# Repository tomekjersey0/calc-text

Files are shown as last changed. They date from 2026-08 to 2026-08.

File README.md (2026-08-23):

# CalcText

## What is CalcText?

CalcText is a wireless messaging device enclosed inside a scientific calculator, powered by a single AAA battery. Two units can message each other directly over LoRa, not requiring Wi-Fi, mobile data, or any kind of external infrastructure. The idea came to me from wanting to message a friend who sat far away from me in my maths class without using my phone or shouting. Despite being a little odd, the idea stuck with me.

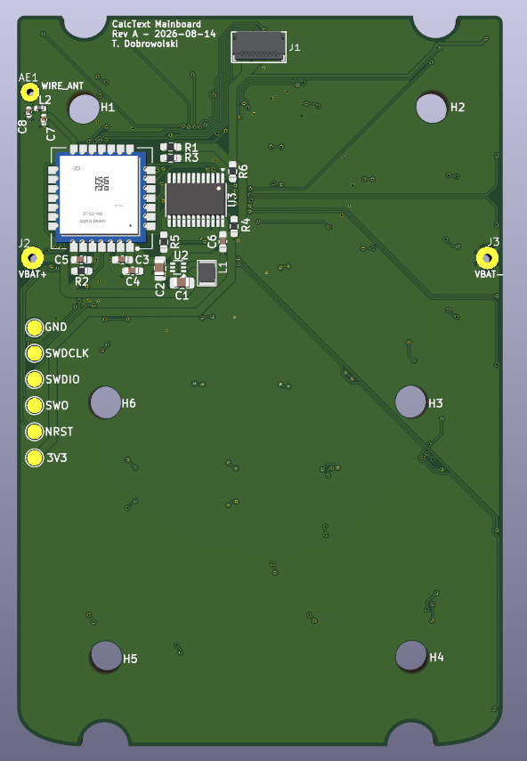
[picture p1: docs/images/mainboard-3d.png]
CalcText Rev A mainboard 3D render


*CalcText Rev A mainboard 3D render.*

## How it works

CalcText replaces all of the internal calculator electronics, including the PCB and LCD screen, whilst making use of some of the existing mechanical features.

CalcText makes use of several electronic components.

| Part | Purpose |
| --- | --- |
| Wio-E5-LE | MCU and LoRa radio module |
| TPS61299 | Boosts AAA voltage to 3.3 V |
| PCAL9535A | GPIO expander, scans original keypad matrix for input |
| HLCD290TB reflective display | Replacement display for calculator |
| Interposer board | Connects display to mainboard |
| ~90 mm wire antenna | Used for 868 MHz LoRa |

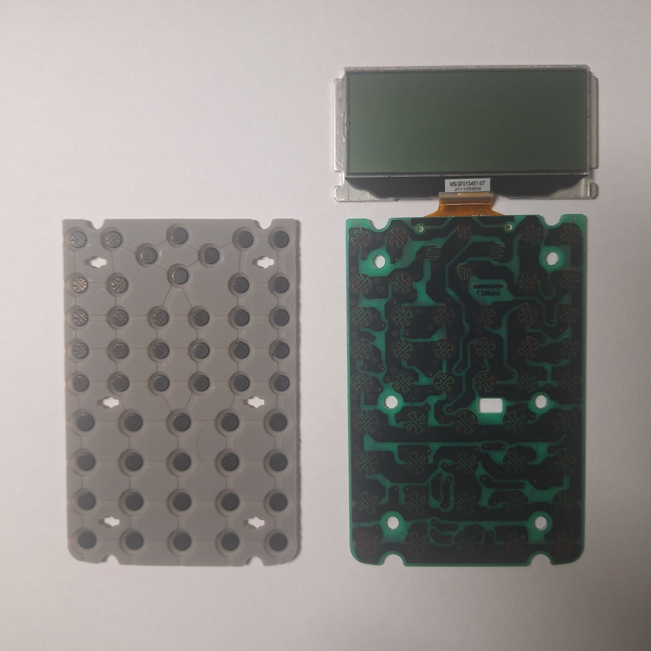
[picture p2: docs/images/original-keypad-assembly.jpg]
Original calculator keypad and PCB


*Original calculator keypad and PCB assembly.*

CalcText makes use of an existing elastomeric keypad that was part of the original calculator. It gives the user a way to interact with the contacts on the PCB. The old contact pattern is therefore replicated on the replacement PCB.

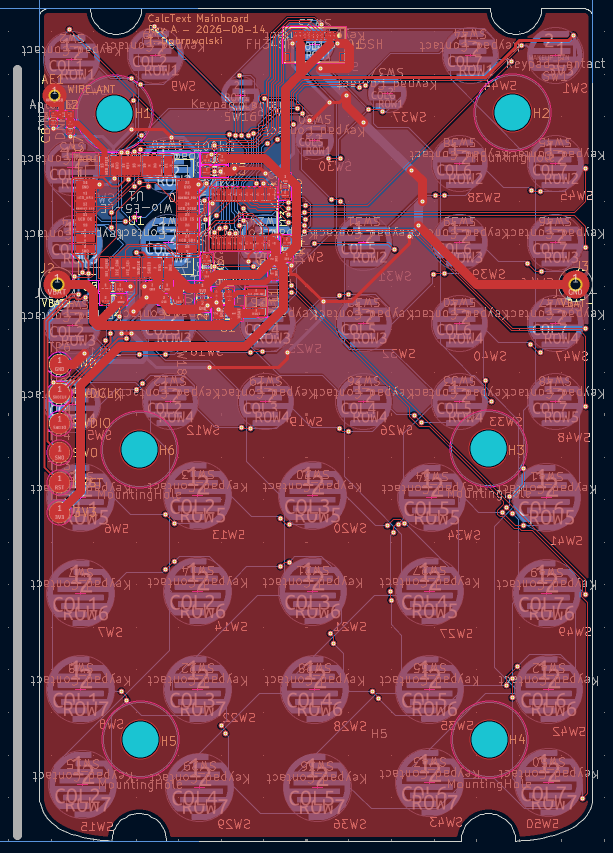
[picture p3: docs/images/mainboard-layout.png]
Rev A mainboard PCB layout


*Rev A mainboard PCB layout.*

A direct FPC connection isn't viable from the reflective display to the mainboard, so an intermediary interposer board is used, to be located on the rear of the display.

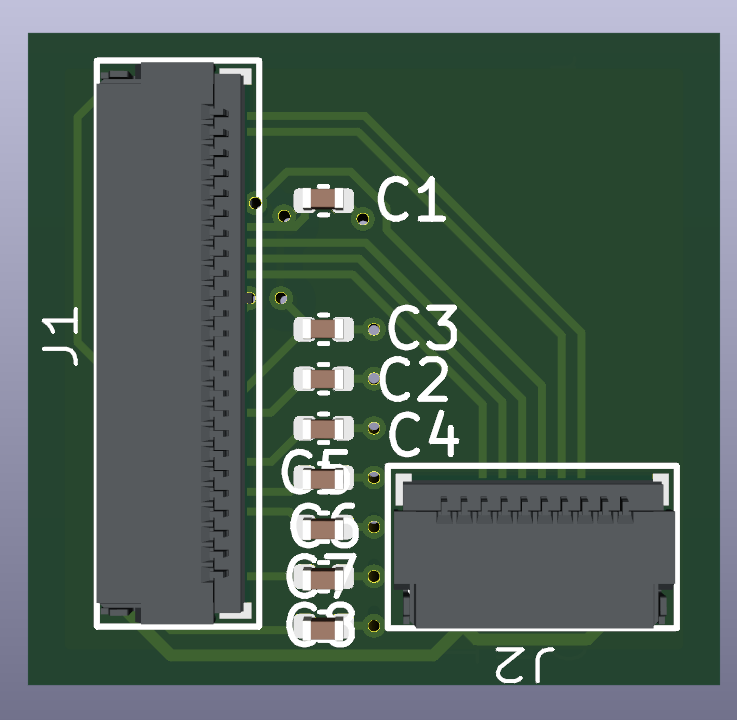
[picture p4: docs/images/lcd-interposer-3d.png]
LCD interposer 3D render


*LCD interposer 3D render.*

## Fitting it inside the calculator

The main challenge is getting everything to fit inside the original enclosure.

| Part to fit | Issue | Resolution |
| --- | --- | --- |
| Mainboard | There are mounting holes, thickness, and outline constraints | Produced acrylic fit test using school equipment and measured original PCB thickness with calipers |
| Display | Larger footprint and thinner than original | Sections of the enclosure can be removed, and PORON foam can secure it |
| Interposer | Unknown FPC landing position due to bend once display is installed | Order screen first and design interposer size based on measured landing position |
| Antenna | Needs sufficient distance from metal and components to ensure good transmission quality | Keep antenna routed down long edge through visible gap, allow it to exit the PCB as far from the display and battery as possible |

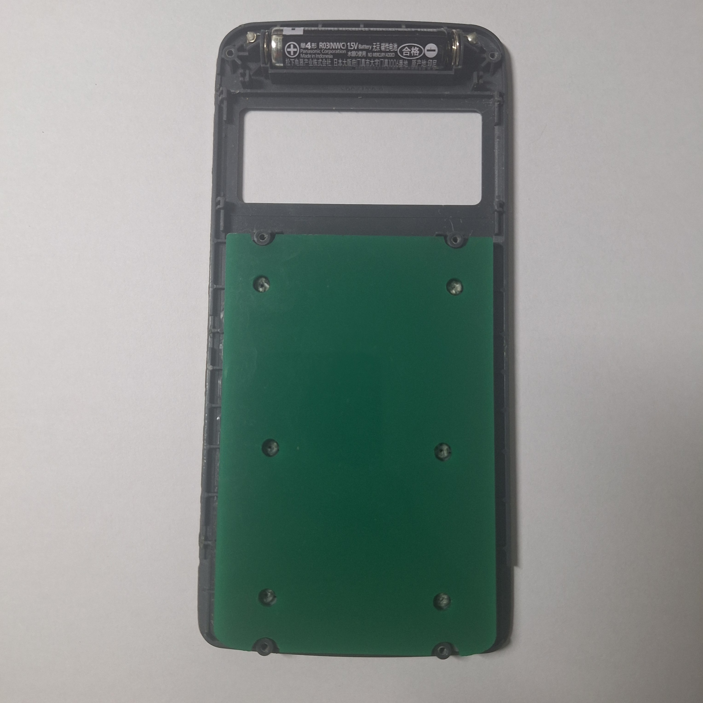
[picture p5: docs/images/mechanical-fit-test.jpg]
Acrylic mainboard fit test inside calculator enclosure


*Acrylic mainboard fit test inside the calculator enclosure + Location of battery.*

## Current status

| Element | Status |
| --- | --- |
| Mainboard schematic | Complete |
| Mainboard layout | Complete |
| Interposer schematic | Complete |
| Interposer layout | Pending display measurements |
| BOM | Complete |
| Physical build | Pending components |
| Funding | Pending review |

## Next steps

1. Submit project for review
2. Order all currently finalised parts
3. Take necessary measurements
4. Complete and order interposer
5. Fully assemble 2 CalcTexts
6. Write firmware
7. Test messaging
8. Tune antenna if necessary
9. Project complete

## BOM

The full BOM can be found in [`bom.csv`](bom.csv).
This BOM covers *two* individual CalcText units.

## Credits

This project was enabled by [Hack Club, Macondo](https://macondo.hackclub.com).

You can access the project's full development journal [here](https://macondo.hackclub.com/projects/16515).

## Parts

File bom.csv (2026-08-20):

Category | Board / Use | Reference | Item | Manufacturer | MPN / Exact spec | Qty per CalcText | Qty for 2 | Owned? | Qty to Buy | Notes
Core electronics | Mainboard | U1 | LoRa MCU module | Seeed Studio | Wio-E5-LE | 1 | 2 | No | 2 | DigiKey cart. Buy exactly 2; no spare currently included.
Power | Mainboard | U2 | Boost converter | Texas Instruments | TPS61299DRLR | 1 | 2 | No | 4 | DigiKey cart: 2 required + 2 spares. Non-A variant is locked.
Keypad | Mainboard | U3 | 16-bit I/O expander | NXP | PCAL9535APW,118 | 1 | 2 | No | 3 | DigiKey cart: 2 required + 1 spare.
Power | Mainboard | L1 | 1 uH power inductor | INPAQ | WIP252010P-1R0ML | 1 | 2 | No | 20 | LCSC C315715. 20-piece MOQ; only 2 required for two units.
RF | Mainboard | L2 | 0 ohm series link | YAGEO | RC0402JR-070RL | 1 | 2 | No | 10 | DigiKey cart: 2 required; buying 10. Keep designator L2.
Power | Mainboard | C1,C2 | 10 uF ceramic capacitor | Samsung Electro-Mechanics | CL21B106KOQNNNE; 10uF ±10%, 16V, X7R, 0805 | 2 | 4 | Yes (20) | 0 | Owned stock.
Decoupling | Mainboard | C3,C5,C6 | 100 nF ceramic capacitor | KEMET | C0603C104K5RACTU; 0.1uF ±10%, 50V, X7R, 0603 | 3 | 6 | Yes (75) | 0 | Owned stock.
Power | Mainboard | C4 | 4.7 uF ceramic capacitor | Samsung Electro-Mechanics | CL10B475KQ8NNNC; 4.7uF ±10%, 6.3V, X7R, 0603 | 1 | 2 | Yes (20) | 0 | Owned stock.
RF | Mainboard | C7,C8 | Pi-network shunt capacitor footprints | — | 0402, DNP | 0 fitted | 0 fitted | N/A | 0 | DNP in Rev A.
Keypad / control | Mainboard | R1-R3 | 100 kOhm resistor | Stackpole Electronics | RMCF0603FT100K | 3 | 6 | Yes (50) | 0 | Owned stock.
Keypad / control | Mainboard | R4-R6 | 10 kOhm resistor | YAGEO | RC0603FR-0710KL | 3 | 6 | Yes (100) | 0 | Owned stock.
Display connection | Mainboard + LCD interposer | Mainboard J1; Interposer J2 | 10-pin FFC connector | Hirose | FH34SRJ-10S-0.5SH(99) | 2 | 4 | No | 5 | DigiKey cart: 4 required + 1 spare. 0.5mm pitch, for 0.3mm FFC.
Display connection | LCD interposer | J1 | 24-pin display FPC connector | Hirose | FH34SRJ-24S-0.5SH(99) | 1 | 2 | No | 3 | DigiKey cart: 2 required + 1 spare. 0.5mm pitch, for ~0.30mm display FPC.
Display decoupling | LCD interposer | C1-C8 | 1 uF ceramic capacitor | TDK | C1005X5R1E105K050BC; 1uF ±10%, 25V, X5R, 0402 | 8 | 16 | No | 25 | DigiKey cart: 16 required; buying 25.
Display | Mechanical / electrical | LCD1 | 2.9in reflective monochrome TFT display | Hicenda | HLCD290TB; ST7305; 168x384; black/white; 24-pin 0.5mm FPC | 1 | 2 | No | 2 | Hicenda has stock. Direct Jersey shipment. Final PI received with correct Jersey delivery address and destination.
RF | Mainboard / enclosure | AE1 | 868 MHz wire antenna | Owned wire | ~86.3mm quarter-wave; insulated solid-core wire ~0.6mm diameter | ~86.3 mm | ~172.6 mm | Yes | 0 | Owned wire is sufficient.
Power / wiring | Mainboard / enclosure | BAT+, BAT- | Battery hookup wire | Owned wire | Insulated solid-core wire ~0.6mm diameter | As needed | As needed | Yes | 0 | Use existing wire stock.
PCB fabrication | Mainboard | PCB | CalcText Rev A mainboard PCB | JLCPCB | 0.8mm, 2-layer, 1oz copper, green soldermask, white silkscreen, HASL with lead | 1 | 2 | No | 5 | JLCPCB minimum/order quantity 5. Current checkout total £3.14 before Ship2Me forwarding.
Donor hardware | Enclosure / keypad | DONOR1 | Compatible donor calculator | Casio / eBay seller | Casio FX-83GTX Scientific Calculator - NO COVER - BLACK | 1 | 2 | Yes (1 donor) | 1 | One donor already owned; buy one additional donor on eBay. Item £14.99, free UK postage, then Ship2Me.
Assembly consumable | Assembly | — | No-clean tack flux | Chip Quik | SMD491-5M | Shared | Shared | No | 1 | DigiKey cart. No-clean, halogen-free tack flux.
Test equipment | Bring-up / debugging | — | Digital multimeter | FLIR Extech | MN35 | Shared | Shared | No | 1 | DigiKey cart. User currently owns no multimeter.
Assembly consumable | Assembly | — | Solder | Owned stock | SW-0650G; 0.6mm; Sn0.7Cu; 2% flux; 50g | Shared | Shared | Yes | 0 | Owned.
Assembly tool | Assembly | — | Soldering station | FEITA | T100A / T12 station | Shared | Shared | Yes | 0 | Owned.
Programming tool | Firmware / bring-up | — | ST-LINK programmer | STMicroelectronics / clone | ST-LINK V2 compatible; SWDIO/SWCLK/NRST/SWO/3V3/GND | Shared | Shared | Yes | 0 | Owned.
HOLD - optional consumable | Power | BT1 | AAA alkaline battery | TBD local | Fresh AAA alkaline | 1 | 2 | 1 on hand | HOLD / maybe | Fresh AAA batteries are not part of the current funding request. Use the battery already on hand for initial work; add/fund fresh batteries later only if actually required.
HOLD - optional consumable | Assembly / cleanup | — | 99% IPA / electronics cleaner | TBD local | 99% isopropyl alcohol or suitable electronics cleaner | Shared | Shared | No | HOLD / outside grant | Not part of the current Macondo funding request. Source locally later if needed for cleanup; do not delay review/submission over this.
Staged mechanical - funded / purchase later | LCD interposer | PCB | Final LCD interposer PCB fabrication | JLCPCB | Estimated same fabrication tier as mainboard: <100x100mm, 0.8mm, 2-layer, 1oz copper, green soldermask, white silkscreen, HASL with lead | 1 | 2 | No | 5 later | Foreseeable complete-build cost and INCLUDED in Macondo funding request, but do not order yet. Final geometry is set after fitting the physical HLCD290TB and locating its natural FPC landing point. Estimated landed cost: £3.14 JLCPCB + £5.95 Ship2Me = £9.09.
Staged mechanical - funded / purchase later | Display link | FFC | 10-way FFC cable | eBay listing | 10-core, 0.5mm pitch, 30mm length, same-side contacts | 1 | 2 | No | 2 later | Foreseeable complete-build cost and INCLUDED in Macondo funding request, but purchase after physical fit. Expected run is about 20-30mm; 30mm same-side cable selected. Current checkout for 2 cables: £6.06 items + £5.24 postage - £0.12 discount = £11.18 delivered to Jersey.
Staged mechanical - funded / purchase later | Display retention | FOAM | PORON / low-force retention foam | Rogers / iParts4U | 4790-79; 3mm x 20m TapeBase reel; soft black display back pad foam | 4 small pads | 8 small pads | No | 1 reel later | Foreseeable complete-build cost and INCLUDED in Macondo funding request. Rogers 4790-79 3mm foam selected as the retention material. Current iParts4U Jersey checkout total: £7.46 delivered (VAT excluded; free standard delivery). Intended arrangement: four small corner pads per LCD; final pad size/placement set after physical fit.
Procurement total | DigiKey order | — | DigiKey cart total | DigiKey | Current checkout total: $97.83 | — | — | No | 1 order | COST EVIDENCE ONLY - not a separate physical BOM item. Direct to Jersey; FedEx International Priority FREE; shipping $0.00. Covers Wio x2, TPS61299 x4, PCAL9535A x3, Hirose 10-pin x5, Hirose 24-pin x3, TDK 1uF x25, 0ohm 0402 x10, Chip Quik flux x1, Extech MN35 x1.
Procurement total | LCSC order | — | LCSC inductor order total | LCSC | Current checkout total: $7.91 | — | — | No | 1 order | COST EVIDENCE ONLY. Merchandise $0.45 + Global Direct Standard Line $4.46 + handling $3.00. Ships to Ship2Me UK.
Procurement total | LCSC forwarding | — | Ship2Me forwarding for LCSC | Ship2Me | Small packet: £5.95 | — | — | No | 1 delivery | COST EVIDENCE ONLY. 25x15x10cm small-packet service.
Procurement total | JLCPCB order | — | JLCPCB mainboard order total | JLCPCB | Current checkout grand total: £3.14 | — | — | No | 1 order | COST EVIDENCE ONLY. Merchandise £1.50 + shipping £1.12 + customs duties/taxes £0.52. Ships to Ship2Me UK.
Procurement total | JLCPCB forwarding | — | Ship2Me forwarding for JLCPCB | Ship2Me | Small packet: £5.95 | — | — | No | 1 delivery | COST EVIDENCE ONLY. 25x15x10cm small-packet service.
Procurement total | Hicenda order | — | Hicenda display order total | Hicenda | $60.90 quoted total | — | — | No | 1 order | COST EVIDENCE ONLY. 2x HLCD290TB at $5.95 each + DHL $49 = $60.90 direct to Jersey. Final PI received with correct Jersey delivery address and destination.
Procurement total | eBay order | — | Second donor calculator order total | eBay / RN Online | £14.99 | — | — | No | 1 order | COST EVIDENCE ONLY. UK postage free; ships to Ship2Me.
Procurement total | eBay forwarding | — | Ship2Me forwarding for donor calculator | Ship2Me | Small packet: £5.95 | — | — | No | 1 delivery | COST EVIDENCE ONLY. Donor calculator fits the 25x15x10cm small-packet tier.
Procurement estimate | LCD interposer PCB order | — | Deferred LCD interposer PCB fabrication estimate | JLCPCB | Estimated JLCPCB checkout: £3.14 | — | — | No | 1 later order | FUNDING ESTIMATE ONLY. Interposer remains <100x100mm and is expected to use the same basic fabrication tier as the mainboard. Purchase deferred until physical display fit fixes the final board geometry.
Procurement estimate | LCD interposer forwarding | — | Ship2Me forwarding estimate for LCD interposer PCBs | Ship2Me | Small packet: £5.95 | — | — | No | 1 later delivery | FUNDING ESTIMATE ONLY. Same 25x15x10cm small-packet tier used for the mainboard PCBs.
Procurement estimate | Display FFC later order | — | 2x 30mm same-side 10-core FFC delivered | eBay listing | Current checkout total: £11.18 | — | — | No | 1 later order | FUNDING ESTIMATE ONLY. 2 cables: £6.06 items + £5.24 postage - £0.12 discount = £11.18 delivered to Jersey.
Procurement total | PORON order | — | Rogers 4790-79 3mm x 20m TapeBase reel | iParts4U | Current checkout total: £7.46 | — | — | No | 1 order | COST EVIDENCE ONLY. Jersey checkout shows £7.46 total with VAT excluded and free standard delivery. One 3mm x 20m reel is far more than required for the small LCD retention pads.
Procurement summary | Current foreseeable build funding stack | — | Current mixed-currency funding total | — | $166.64 + £63.71 | — | — | — | — | Includes DigiKey, LCSC + forwarding, JLCPCB mainboards + forwarding, Hicenda, eBay donor + forwarding, the foreseeable later interposer PCB (£9.09 landed), FFC order (£11.18 delivered), and Rogers PORON (£7.46 delivered). Fresh AAA batteries and IPA/cleaner remain outside the current grant.

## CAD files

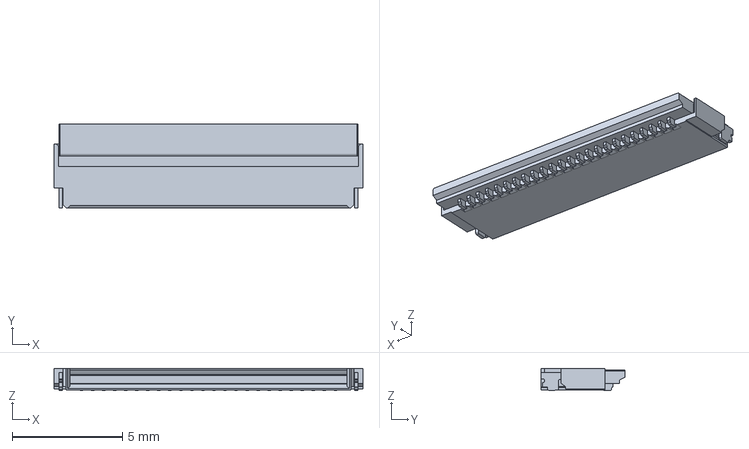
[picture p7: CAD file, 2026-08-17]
hardware/3d/FH34SRJ-24S-0.5SH.stp
14.0 x 3.80 x 1.00 mm

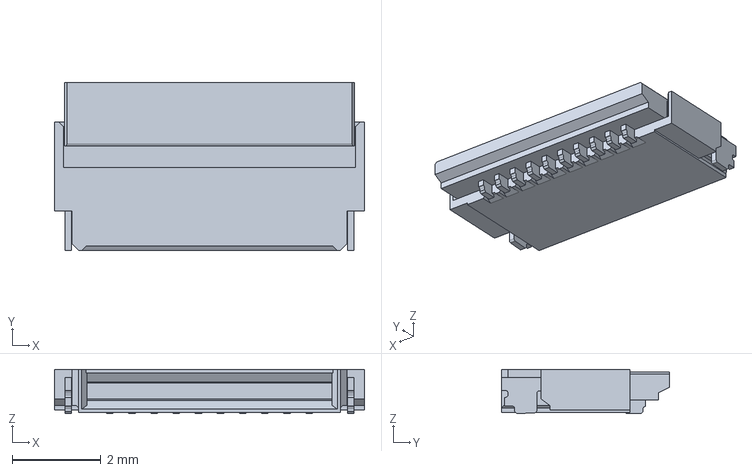
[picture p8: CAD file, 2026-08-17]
hardware/3d/FH34SRJ-10S-0.5SH.stp
7.00 x 3.80 x 1.00 mm

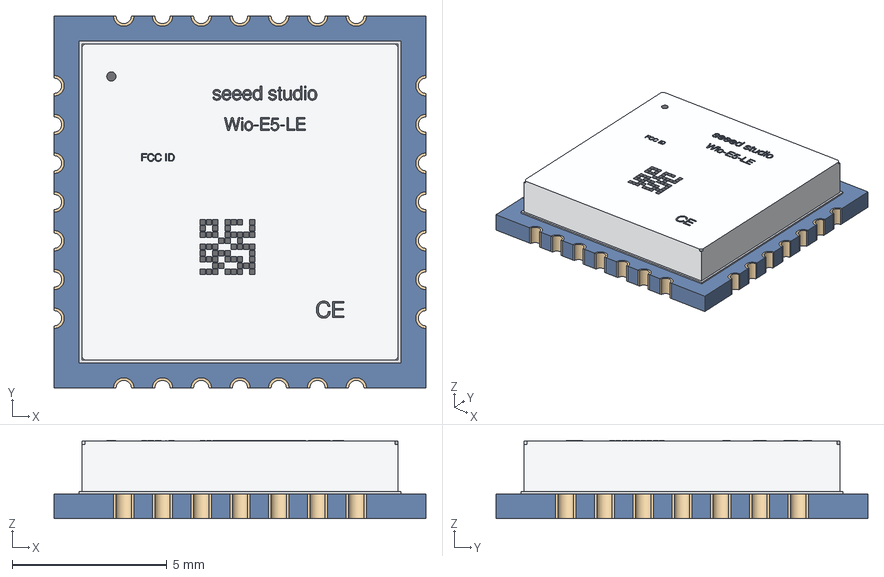
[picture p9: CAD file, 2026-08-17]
hardware/3d/Wio-E5-LE.step
12.0 x 12.0 x 2.53 mm
Blue_Substrate
Plated_Castellation_Sleeves
Shield_Base_Flange
Stamped_RF_Shield
Top_Print

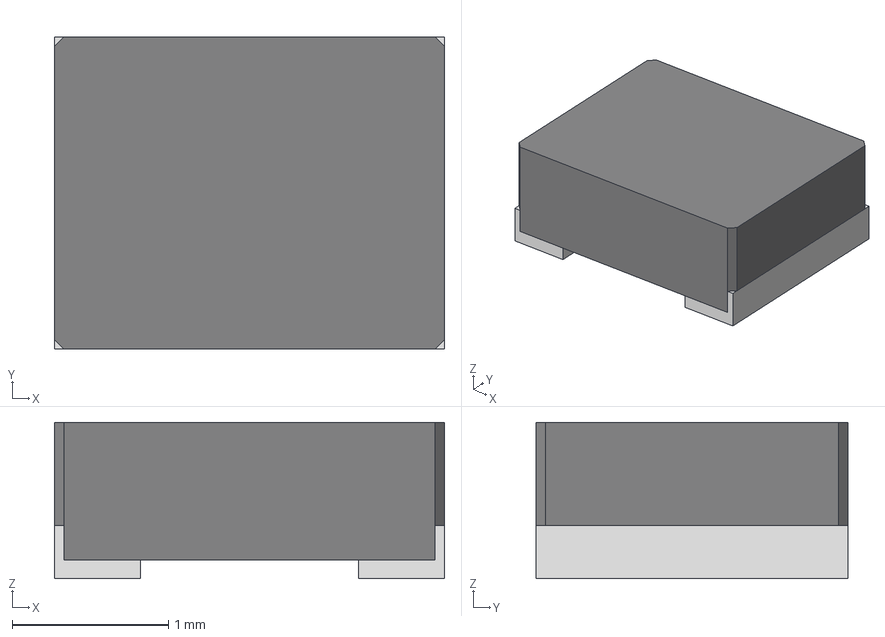
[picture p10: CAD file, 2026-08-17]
hardware/3d/INPAQ-WIP252010P-1R0ML.step
2.50 x 2.00 x 1.00 mm
Molded_Body
Terminations

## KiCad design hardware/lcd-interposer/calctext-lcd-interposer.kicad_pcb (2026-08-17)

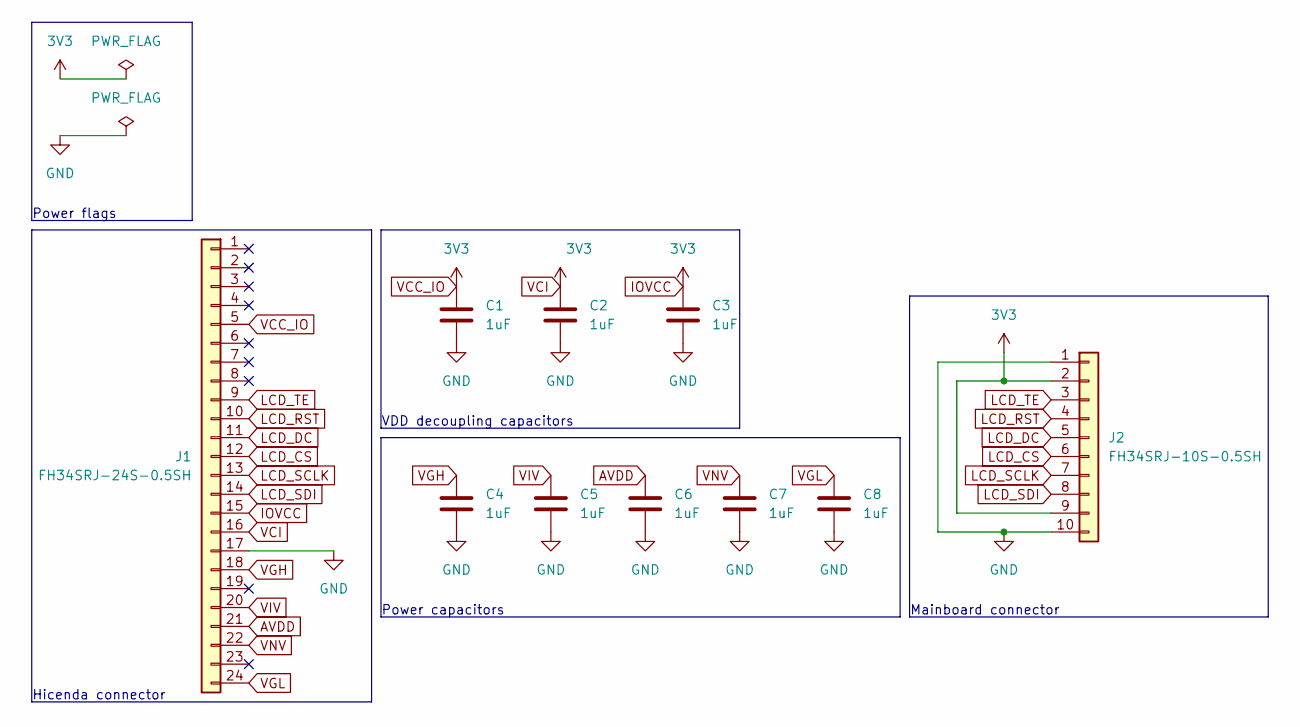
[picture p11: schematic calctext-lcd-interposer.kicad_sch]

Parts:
C1, C2, C3, C4, C5, C6, C7, C8: 1uF; C_0402_1005Metric; MPN C1005X5R1E105K050BC
J1: FH34SRJ-24S-0.5SH; Hirose_FH34SRJ-24S-0.5SH; MPN FH34SRJ-24S-0.5SH(99)
J2: FH34SRJ-10S-0.5SH; Hirose_FH34SRJ-10S-0.5SH; MPN FH34SRJ-10S-0.5SH(99)

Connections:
AVDD: C6.2, J1.21
GND: C1.1, C2.1, C3.1, C4.1, C5.1, C6.1, C7.1, C8.1, J1.17, J2.1 (3.3V), J2.10 (GND_P)
IOVCC: C1.2, C2.2, C3.2, J1.5, J1.15, J1.16, J2.2 (GND_L), J2.9 (VBIAS)
LCD_CS: J1.12, J2.6 (DC)
LCD_DC: J1.11, J2.5 (NSS)
LCD_RST: J1.10, J2.4 (MOSI)
LCD_SCLK: J1.13, J2.7 (RESET)
LCD_SDI: J1.14, J2.8 (PWM)
LCD_TE: J1.9, J2.3 (SCK)
VGH: C4.2, J1.18
VGL: C8.2, J1.24
VIV: C5.2, J1.20
VNV: C7.2, J1.22

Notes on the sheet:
VDD decoupling capacitors
Hicenda connector
Power capacitors
Mainboard connector
Power flags

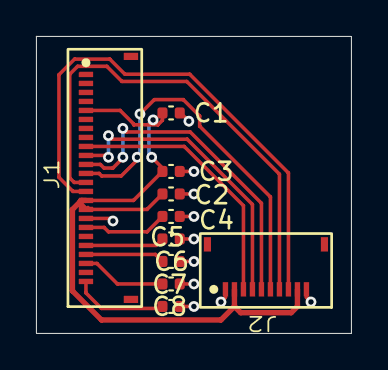
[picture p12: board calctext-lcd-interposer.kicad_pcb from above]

Board: 2 copper layers, 17.5 x 16.5 mm, 10 parts (0 on the bottom side), 13 nets.

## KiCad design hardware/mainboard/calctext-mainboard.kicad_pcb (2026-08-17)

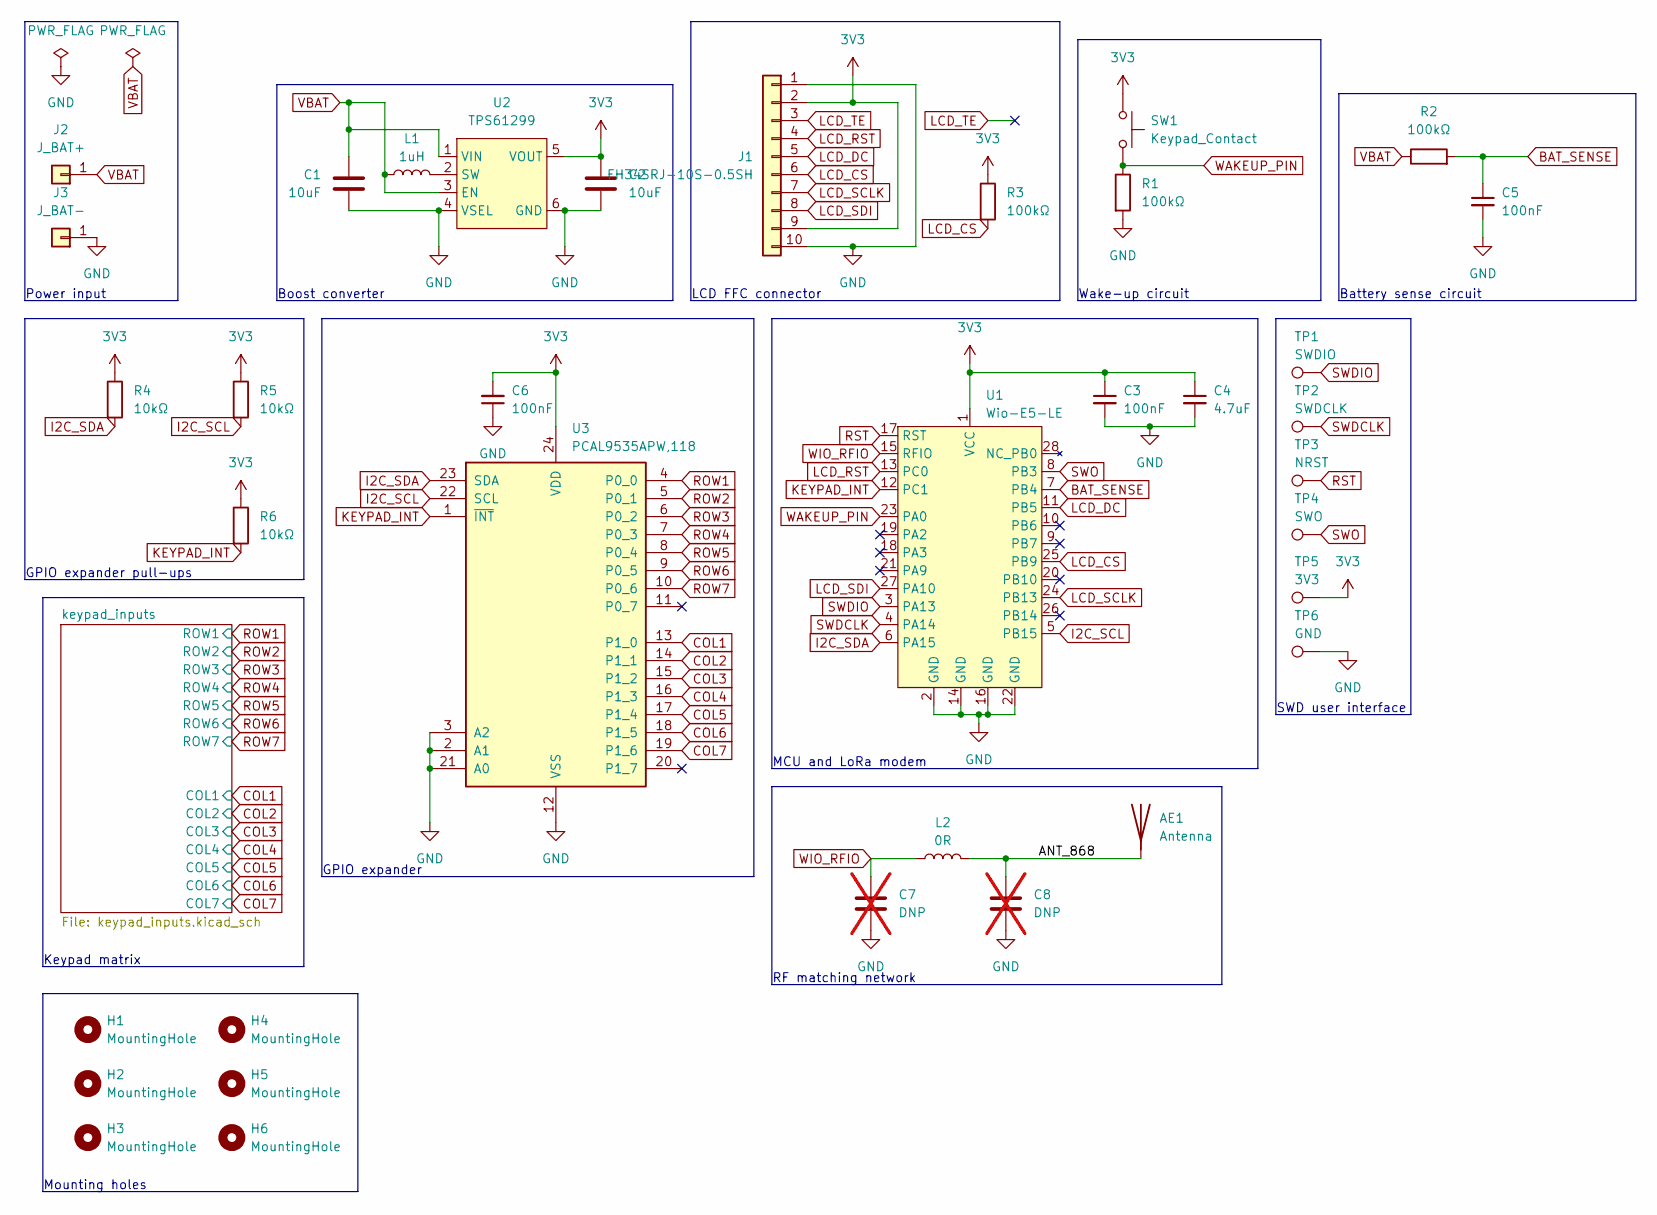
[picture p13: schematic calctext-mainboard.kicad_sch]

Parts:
AE1: Antenna; Wire_Antenna_PTH
C1, C2: 10uF; C_0805_2012Metric_Pad1.18x1.45mm_HandSolder; MPN CL21B106KOQNNNE
C3, C5, C6: 100nF; C_0603_1608Metric_Pad1.08x0.95mm_HandSolder; MPN C0603C104K5RACTU
C4: 4.7uF; C_0603_1608Metric_Pad1.08x0.95mm_HandSolder; MPN CL10B475KQ8NNNC
C7, C8: DNP; C_0402_1005Metric; not fitted
H1, H2, H3, H4, H5, H6: MountingHole; MountingHole_4.3mm_M4
J1: FH34SRJ-10S-0.5SH; Hirose_FH34SRJ-10S-0.5SH; MPN FH34SRJ-10S-0.5SH(99)
J2: J_BAT+; Wire_Solder_PTH
J3: J_BAT-; Wire_Solder_PTH
L1: 1uH; L_INPAQ_WIP252010; MPN WIP252010P-1R0ML
L2: 0R; L_0402_1005Metric; MPN RC0402JR-070RL
R1, R2, R3: 100kΩ; R_0603_1608Metric_Pad0.98x0.95mm_HandSolder; MPN RMCF0603FT100K
R4, R5, R6: 10kΩ; R_0603_1608Metric_Pad0.98x0.95mm_HandSolder; MPN RC0603FR-0710KL
SW1: Keypad_Contact
TP1: SWDIO; TestPoint_Pad_D2.0mm
TP2: SWDCLK; TestPoint_Pad_D2.0mm
TP3: NRST; TestPoint_Pad_D2.0mm
TP4: SWO; TestPoint_Pad_D2.0mm
TP5: 3V3; TestPoint_Pad_D2.0mm
TP6: GND; TestPoint_Pad_D2.0mm
U1: Wio-E5-LE; MPN Wio-E5-LE
U2: TPS61299; Texas_R-PDSO-N6_DRL-6; MPN TPS61299DRLR
U3: PCAL9535APW,118; TSSOP-24_4.4x7.8mm_P0.65mm; MPN PCAL9535APW,118

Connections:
3V3: C2.1, C3.1, C4.1, C6.2, J1.2 (GND_L), J1.9 (VBIAS), R3.1, R4.1, R5.1, R6.1, SW1.1, TP5.1, U1.1 (VCC), U2.5 (VOUT), U3.24 (VDD)
/ANT_868: AE1.1 (A), C8.1, L2.2
BAT_SENSE: C5.1, R2.2, U1.7 (PB4)
COL1: U3.13 (P1_0); also elsewhere on the board
COL2: U3.14 (P1_1); also elsewhere on the board
COL3: U3.15 (P1_2); also elsewhere on the board
COL4: U3.16 (P1_3); also elsewhere on the board
COL5: U3.17 (P1_4); also elsewhere on the board
COL6: U3.18 (P1_5); also elsewhere on the board
COL7: U3.19 (P1_6); also elsewhere on the board
GND: C1.2, C2.2, C3.2, C4.2, C5.2, C6.1, C7.2, C8.2, J1.1 (3.3V), J1.10 (GND_P), J3.1, R1.2, TP6.1, U1.2 (GND), U1.14 (GND), U1.16 (GND), U1.22 (GND), U2.4 (VSEL), U2.6 (GND), U3.2 (A1), U3.3 (A2), U3.12 (VSS), U3.21 (A0)
I2C_SCL: R5.2, U1.5 (PB15), U3.22 (SCL)
I2C_SDA: R4.2, U1.6 (PA15), U3.23 (SDA)
KEYPAD_INT: R6.2, U1.12 (PC1), U3.1 (~INT)
LCD_CS: J1.6 (DC), R3.2, U1.25 (PB9)
LCD_DC: J1.5 (NSS), U1.11 (PB5)
LCD_RST: J1.4 (MOSI), U1.13 (PC0)
LCD_SCLK: J1.7 (RESET), U1.24 (PB13)
LCD_SDI: J1.8 (PWM), U1.27 (PA10)
LCD_TE: J1.3 (SCK)
unnamed: L1.2, U2.2 (SW)
ROW1: U3.4 (P0_0); also elsewhere on the board
ROW2: U3.5 (P0_1); also elsewhere on the board
ROW3: U3.6 (P0_2); also elsewhere on the board
ROW4: U3.7 (P0_3); also elsewhere on the board
ROW5: U3.8 (P0_4); also elsewhere on the board
ROW6: U3.9 (P0_5); also elsewhere on the board
ROW7: U3.10 (P0_6); also elsewhere on the board
RST: TP3.1, U1.17 (RST)
SWDCLK: TP2.1, U1.4 (PA14)
SWDIO: TP1.1, U1.3 (PA13)
SWO: TP4.1, U1.8 (PB3)
VBAT: C1.1, J2.1, L1.1, R2.1, U2.1 (VIN), U2.3 (EN)
WAKEUP_PIN: R1.1, SW1.2, U1.23 (PA0)
WIO_RFIO: C7.1, L2.1, U1.15 (RFIO)

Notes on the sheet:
Keypad matrix
Wake-up circuit
Power input
GPIO expander pull-ups
Boost converter
MCU and LoRa modem
GPIO expander
LCD FFC connector
SWD user interface
RF matching network
Mounting holes
Battery sense circuit

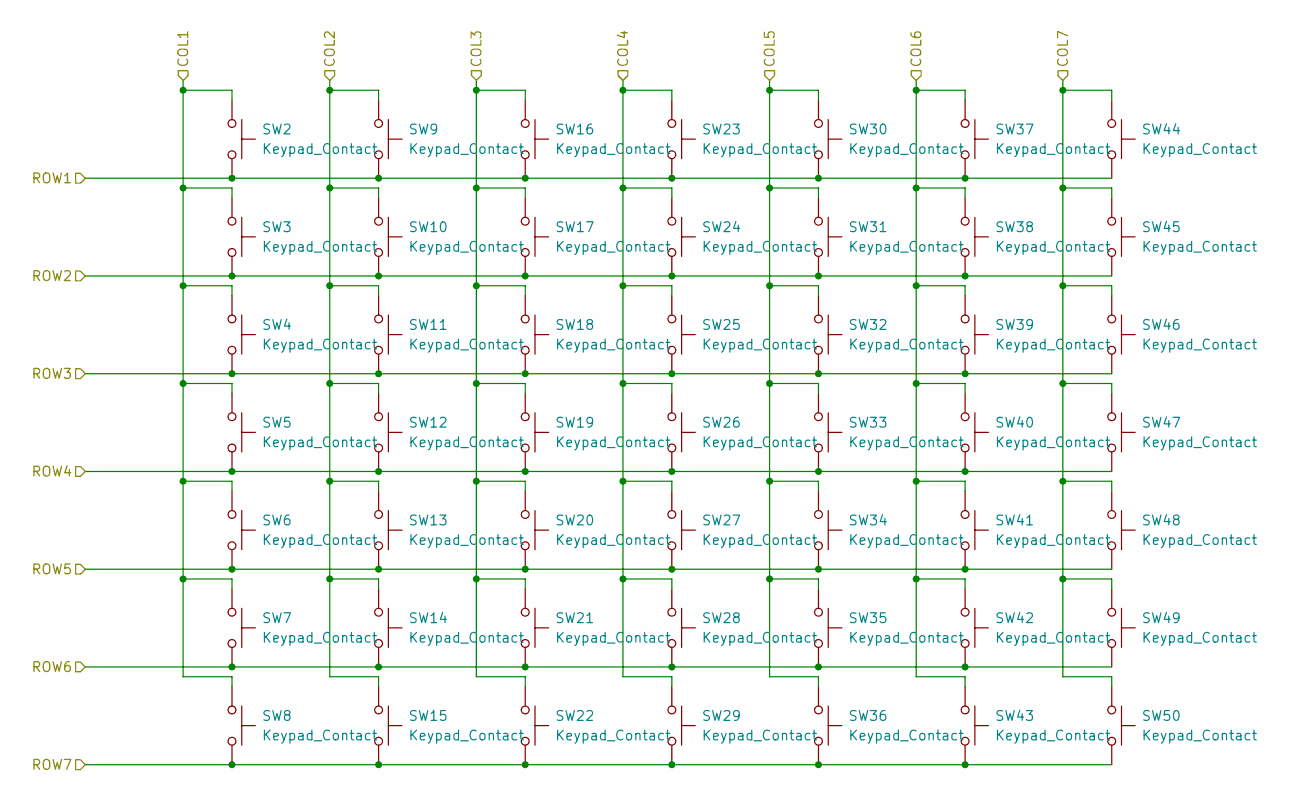
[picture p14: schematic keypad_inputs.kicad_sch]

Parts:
SW2, SW3, SW4, SW5, SW6, SW7, SW8, SW9, SW10, SW11, SW12, SW13, SW14, SW15, SW16, SW17, SW18, SW19, SW20, SW21, SW22, SW23, SW24, SW25, SW26, SW27, SW28, SW29, SW30, SW31, SW32, SW33, SW34, SW35, SW36, SW37, SW38, SW39, SW40, SW41, SW42, SW43, SW44, SW45, SW46, SW47, SW48, SW49, SW50: Keypad_Contact

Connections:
COL1: SW2.1, SW3.1, SW4.1, SW5.1, SW6.1, SW7.1, SW8.1; also elsewhere on the board
COL2: SW9.1, SW10.1, SW11.1, SW12.1, SW13.1, SW14.1, SW15.1; also elsewhere on the board
COL3: SW16.1, SW17.1, SW18.1, SW19.1, SW20.1, SW21.1, SW22.1; also elsewhere on the board
COL4: SW23.1, SW24.1, SW25.1, SW26.1, SW27.1, SW28.1, SW29.1; also elsewhere on the board
COL5: SW30.1, SW31.1, SW32.1, SW33.1, SW34.1, SW35.1, SW36.1; also elsewhere on the board
COL6: SW37.1, SW38.1, SW39.1, SW40.1, SW41.1, SW42.1, SW43.1; also elsewhere on the board
COL7: SW44.1, SW45.1, SW46.1, SW47.1, SW48.1, SW49.1, SW50.1; also elsewhere on the board
ROW1: SW2.2, SW9.2, SW16.2, SW23.2, SW30.2, SW37.2, SW44.2; also elsewhere on the board
ROW2: SW3.2, SW10.2, SW17.2, SW24.2, SW31.2, SW38.2, SW45.2; also elsewhere on the board
ROW3: SW4.2, SW11.2, SW18.2, SW25.2, SW32.2, SW39.2, SW46.2; also elsewhere on the board
ROW4: SW5.2, SW12.2, SW19.2, SW26.2, SW33.2, SW40.2, SW47.2; also elsewhere on the board
ROW5: SW6.2, SW13.2, SW20.2, SW27.2, SW34.2, SW41.2, SW48.2; also elsewhere on the board
ROW6: SW7.2, SW14.2, SW21.2, SW28.2, SW35.2, SW42.2, SW49.2; also elsewhere on the board
ROW7: SW8.2, SW15.2, SW22.2, SW29.2, SW36.2, SW43.2, SW50.2; also elsewhere on the board

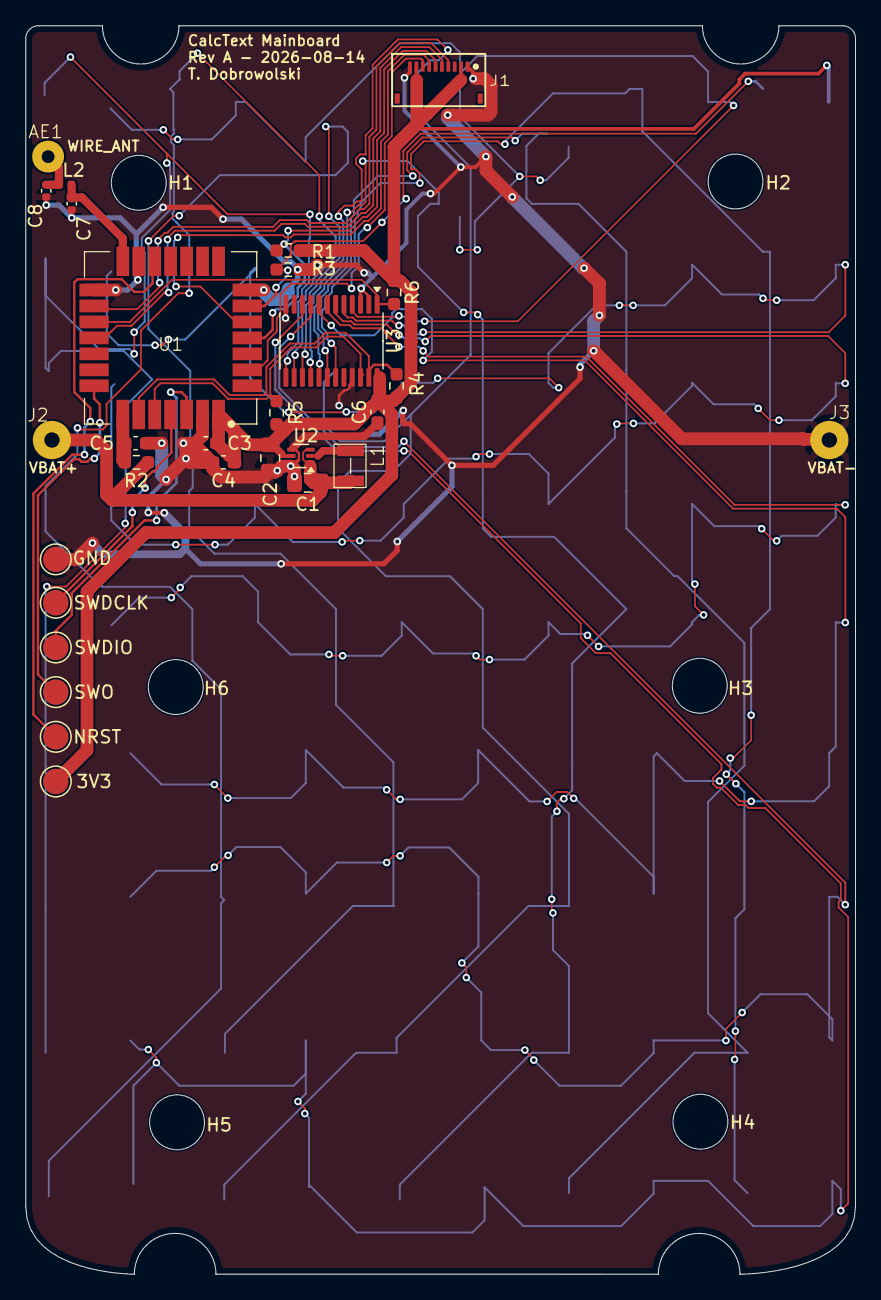
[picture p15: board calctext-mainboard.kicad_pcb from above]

Board: 4 copper layers, 65.0 x 97.8 mm, 85 parts (0 on the bottom side), 34 nets.

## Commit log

2026-03-24 fix: move mounting holes
    [calc text rev1.kicad_pcb, calc text rev1.kicad_sch]
2026-03-24 fix: move bottom holes up 2.7 right 1.0mm
    [calc text rev1.kicad_pcb]
2026-03-24 refactor: remove most of annoying fab marks
    [calc text rev1.kicad_pcb]
2026-03-24 feat: fillet edges of outline
    [calc text rev1.kicad_pcb]
2026-03-24 feat: fillet edges + good holes
    [calc text rev1.kicad_pcb]
2026-03-25 fix: adjust bottom two holes
    [calc text rev1.kicad_pcb]
2026-03-26 refactor: set hole size to 4.3mm
    [calc text rev1.kicad_pcb, calc text rev1.kicad_sch]
2026-08-09 Add CalcText V1 mainboard architecture
    Set up the core hardware design around the Wio-E5-LE and calculator enclosure.
    [calc text rev1.kicad_pcb, calc text rev1.kicad_sch]
2026-08-09 Rename CalcText mainboard KiCad files
    [calctext-mainboard.kicad_pcb, calctext-mainboard.kicad_sch]
2026-08-09 Ignore KiCad local and backup files
2026-08-09 Ignore KiCad generated files
2026-08-10 Design Rev A LCD interposer PCB
    [calctext-lcd-interposer.kicad_pcb, calctext-lcd-interposer.kicad_sch]
2026-08-10 Stop tracking KiCad generated files
2026-08-10 Add keypad I/O expander interface
    [calctext-mainboard.kicad_sch]
2026-08-11 Refine LCD interposer power routing
    [calctext-lcd-interposer.kicad_pcb]
2026-08-11 Consolidate mainboard footprint library
2026-08-11 Add keypad carbon contact footprints
2026-08-11 Add 7x7 keypad matrix schematic
    [calctext-mainboard.kicad_sch, keypad_inputs.kicad_sch]
2026-08-11 Lay out calculator keypad contacts
    [calctext-mainboard.kicad_pcb]
2026-08-13 Reorganize shared hardware libraries
    [calctext-lcd-interposer.kicad_pcb, calctext-lcd-interposer.kicad_sch]
2026-08-13 Refine keypad contacts and mechanical alignment
    [calctext-mainboard.kicad_pcb, keypad_inputs.kicad_sch]
2026-08-13 Add wire termination footprints
2026-08-13 Complete mainboard RF and debug interfaces
    [calctext-mainboard.kicad_sch]
2026-08-13 Polish mainboard schematic presentation
    [calctext-mainboard.kicad_sch]
2026-08-14 Update mainboard power inductor
    [calctext-mainboard.kicad_sch]
2026-08-14 Clean up Wio module footprint
2026-08-14 Complete mainboard PCB layout
    [calctext-mainboard.kicad_pcb]
2026-08-16 Refine hardware for fabrication and procurement
    [calctext-lcd-interposer.kicad_sch, calctext-mainboard.kicad_pcb, calctext-mainboard.kicad_sch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]
2026-08-16 Update procurement BOM and funding costs
    [bom.csv]
2026-08-17 Polish footprints and add 3D models
    [FH34SRJ-10S-0.5SH.stp, FH34SRJ-24S-0.5SH.stp, INPAQ-WIP252010P-1R0ML.step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]
2026-08-17 Finalise hardware sanity-check cleanup
    [calctext-lcd-interposer.kicad_pcb, calctext-lcd-interposer.kicad_sch, calctext-mainboard.kicad_pcb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]
2026-08-17 Add staged build costs to procurement BOM
    [bom.csv]
2026-08-17 Sync interposer connector 3D models
    [calctext-lcd-interposer.kicad_pcb]
2026-08-17 Add submission banner and Rev A Gerber export
2026-08-20 Update final CalcText funding BOM
    [bom.csv]
